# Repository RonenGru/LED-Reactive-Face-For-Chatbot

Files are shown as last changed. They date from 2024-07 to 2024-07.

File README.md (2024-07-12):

# LED-Reactive-Face-For-Chatbot

**Reactive Face: A 256-LED Matrix Animation**

**Overview**
--------

The Reactive Face project is an innovative display that combines animation and interactivity. This open-source project features a 16x16 LED matrix, consisting of 256 LEDs, which can be controlled to create a simple yet engaging face.

**Description**
------------

In this implementation, the face responds to audio inputs by moving its mouth and blinking its eyes. The mouth movement is triggered by sound waves, creating a basic form of expression.

**Features**

* 256-LED matrix display
* Reactive mouth animation triggered by audio input (using ESP32's)
* Eye blinking effect

**Components**
-------------

    • Two ESP32 microcontrollers
    • A 16x16 LED Pixel Panel
    • 2 solderable breadboards
    • An INMP441 Omnidirectional Microphone
    • A rocker switch
    • A DC jack
    • A Max98357 I2S 3W Amplifier Breakout Interface Module
    • A 3W 8Ohm micro speaker
    • A 5V 2A power supply adapter
    • Various jumper cables and screws
    • A 3D printed box

**Contributions**
---------------

I welcome contributions to this project! If you'd like to add features or improve the animation, please feel free to fork this repository and submit your changes.

**License**
----------

This project is licensed under Apache License:  https://www.apache.org/licenses/LICENSE-2.0

IMAGE ALT TEXT HERE (https://www.youtube.com/watch?v=MB5m8CV_g5Y)

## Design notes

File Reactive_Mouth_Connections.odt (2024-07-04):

COMPONENTS & CONNECTIONS

ESP32 #1

Vin 5v to 5v Rail on Breadboard

GND 5v side to Ground on Breadboard

3V3 to 3v Rail on Breadboard

GND 3v side to GND 3v side on Breadboard

LED

Green (data line) D12

White (Ground)

Red (Power Rail 5v)

MICROPHONE

L/R to Ground (3v side)

GND to Ground (3v side)

VOD to 3v Rail

WS to D13

SCK to D14

SD to D32

CAPACITOR

Put on 5v Rail after the power connections. Make sure to put the ground side of the capacitor on the ground rail of the breadboard.

POWER WIRES LINKING TWO BREADBOARDS

Two female jumper cables on the LED ESP32, two male jumper cables on the second breadboard with the ESP32 linked to the Max98357 I2S linked to microphone.

ESP32#2

Vin 5v to 5v Rail on Breadboard

GND 5v side to Ground on Breadboard

3V3 to 3v Rail on Breadboard

GND 3v side to GND 3v side on Breadboard

MAX98357 I2S

Vin to 3v side on breadboard

GND to Ground on 3v side of breadboard

BCK (BCLK) connect to GPIO 26

WS (LRC) connect to GPIO 25

DOUT (DIN) connect to GPIO 27

SPEAKER

Positive wire (solid red) to Positive connection on Max98357

Negative wire (black & red) to ground connection on Max98357

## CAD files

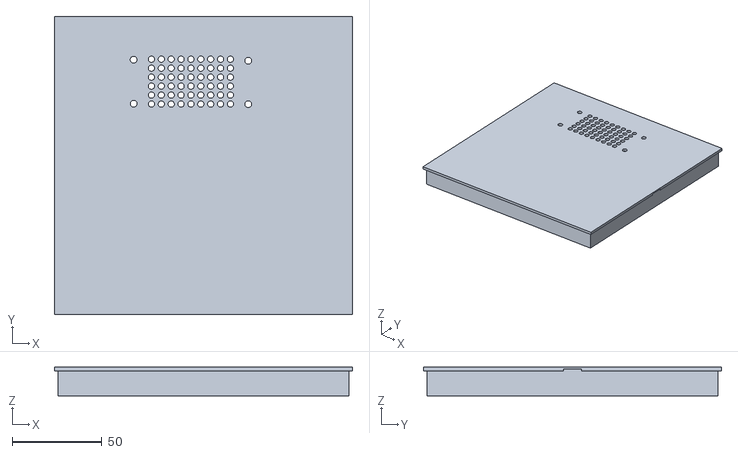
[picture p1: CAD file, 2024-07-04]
Reactive_Mouth_Top_Cover_Audio_Sound_Holes.stl
166.0 x 166.0 x 15.9

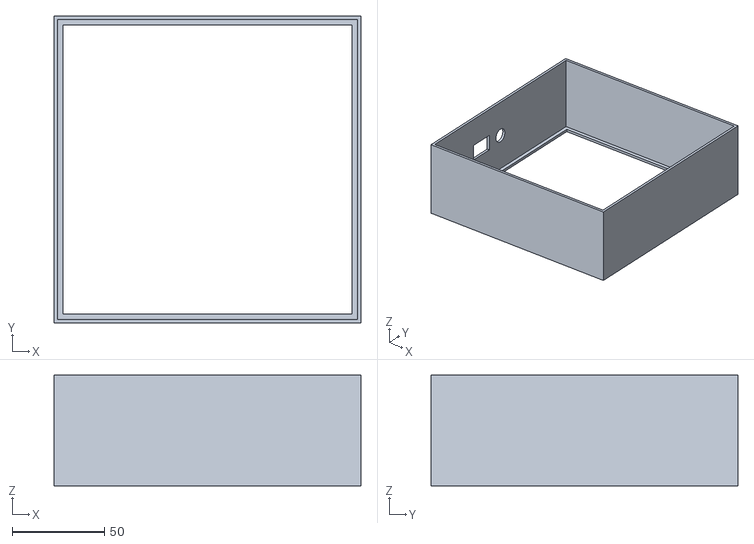
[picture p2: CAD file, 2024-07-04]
Reactive_Mouth_Case_With_Barrel_Jack_and_Rocker_Switch.stl
166.0 x 166.0 x 60.0

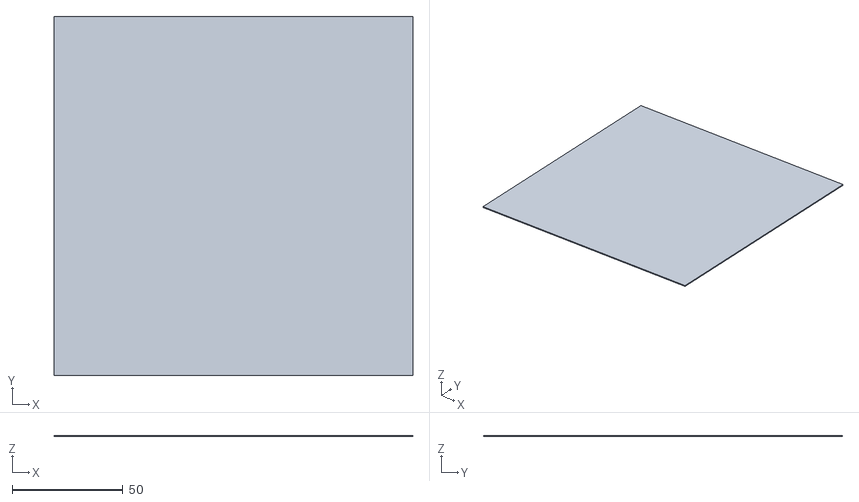
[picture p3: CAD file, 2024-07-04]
Reactive_Mouth_Diffuser.stl
162.2 x 162.2 x 0.6

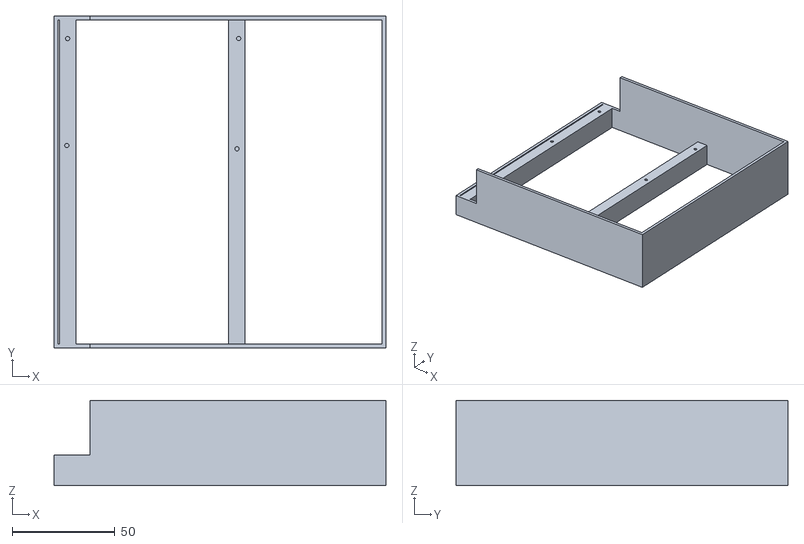
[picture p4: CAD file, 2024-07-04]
Reactive_Mouth_Electronics_Support.stl
161.5 x 161.5 x 41.6

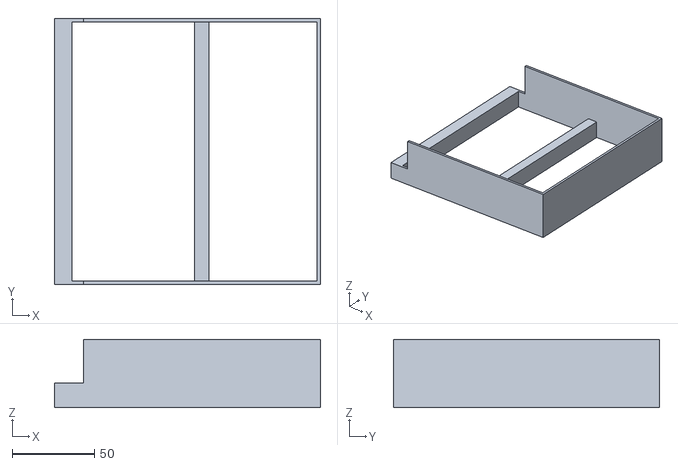
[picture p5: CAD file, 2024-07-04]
Reactive_Mouth_Electronics_Support_No_Screw_Holes.stl
161.5 x 161.5 x 41.6

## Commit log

2024-07-04 Create Code Audio ESP32 #2
2024-07-04 Rename Code Animated Mouth to Code Animated Mouth ESP32 #1
